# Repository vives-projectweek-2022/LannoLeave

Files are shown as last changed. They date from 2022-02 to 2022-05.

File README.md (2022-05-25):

# Lannooleaf

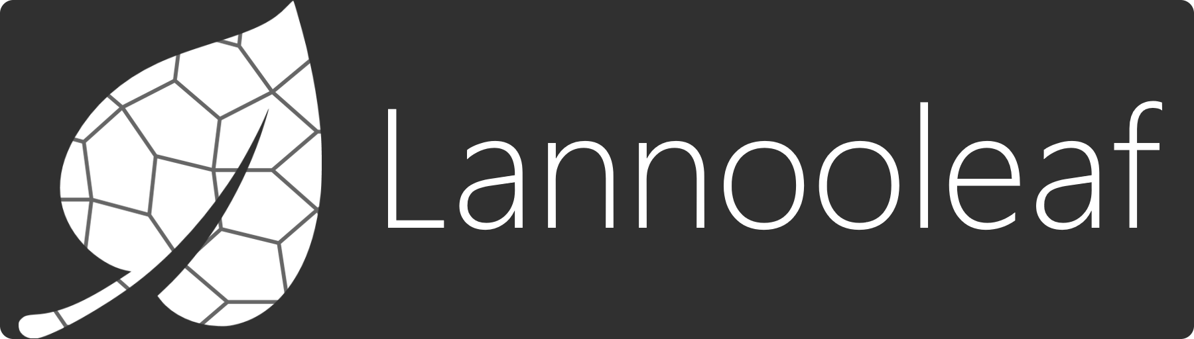
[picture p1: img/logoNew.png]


> VIVES Project Week 2022

## Project overview

<!-- bijwerken -->

* Connectable 3D-printed leaves
* PCB-design with LEDs & communications
* Use an OTS or own communication protocol
* Webpage
* Control of leds

## [Hardware](./hardware)

### [Shape](./hardware/shape/)

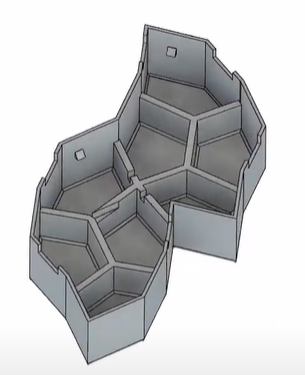
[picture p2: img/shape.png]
shape


Dit is onze shape. Een primitive unit met 8 leafs.

### [PCB](./hardware/pcb/)

<!-- afbeelding hardware -->

Iedere PCB bevat elk 16 RGB LED's en beschikken ieder over een eigen Raspberry Pi Pico en spanningsomzetter. De volledige documentatie over de hardware kan men [hier](./hardware/pcb/README.md) terugvinden.

## [Firmware](./firmware)

<!-- Joey, afbeelding Pico? -->

<!-- aanvullen -->

De firmware documentatie wordt automatisch gegenereed tijdens het build procces van de firmware. Deze is te vinden in de [firmware](./firmware/) folder waar het build procces word uitgelegd.

## [Software](./software/)

The [API](./software/api) connect with the SPI interface and communicates with the frontend, artnet and has a socket to run python processed gifs.

The [ArtNet](./software/artnet) api reicieves artnet broadcast messages ans sends them trough the websochet of the api to controll all the leds. The api mapps them depending on the coords.

The [Frontend](./software/frontend) from Jay is the webinterface and all of its files.

## Credits

### Team Members

* [Arno Schoutteten](https://github.com/madness007)
* [Jens Vanhove](https://github.com/JensVA)
* [Joey De Smet](https://github.com/JoeyDeSmet)
* [Jay D'Hulster](https://github.com/JayDHulster)

### Mentors

* [Nico De Witte](https://github.com/BioBoost)
* [Piet Cordemans](https://github.com/pcordemans)
* [Sille Van Landschoot](https://github.com/sillevl)
* [Jonas Lannoo](https://github.com/JonasLannoo)

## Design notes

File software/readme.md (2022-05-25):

# Software

## API

The [API](./api) connect with the SPI interface and communicates with the frontend, artnet and has a socket to run python processed gifs.

## ArtNet

The [ArtNet](./artnet) api reicieves artnet broadcast messages ans sends them trough the websochet of the api to controll all the leds. The api mapps them depending on the coords.

I used QLC+ (Que Light Controller plus) This is a freeware ArtNet DMX controller. There's a demo show in this directory.

ArtNet is an open protocoll that uses broadcast. So the controller sends messages thru an interface and broadcasts them in the subnet. That way everyone in the subnet can reicieve them.

This protocol is meant to run on isolated networks and is made for network noobs. It is easy to use, but not secure.

## Frontend

The [Frontend](./frontend) from Jay is the webinterface and all of its files.

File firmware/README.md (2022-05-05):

# Lannooleaf firmware

## Building the project

**Info**: The installation guide will only go over how to install tools on a debian based linux system. To build on other platforms you will have to figure that out ;).

### Requirements
- Cmake (Version >= 3.13)
- gcc-arm-none-eabi (Version used 10.2.1)
- Linux build-essentials
- Raspberry Pi Pico [sdk](https://github.com/raspberrypi/pico-sdk)
- (Optional) Visual Studio Code CMake Tools [extention](https://code.visualstudio.com/docs/cpp/cmake-linux)

#### Installing requirements

```bash
sudo apt install cmake gcc-arm-none-eabi libnewlib-arm-none-eabi build-essentials
```

**Pico-sdk**: For installation of Raspberry Pi Pico sdk reffer to there [github page](https://github.com/raspberrypi/pico-sdk)

### Building

```bash
cd /PATH/TO/Lannooleaf/firmware/
```

```bash
mkdir build
cd build
cmake ..
cmake --build .
```

Or use Visual Studio Code CMake extention to build project with a single press of a [button](https://bitly.com/98K8eH)

## Building documentation

This project automatacly generates API documentation using Doxygen and Sphinx.

If you do not want to use Sphinx, then the doxygen generated html files will be placed in /Lannooleaf/firmware/docs/Doxygen/gen_docs/html folder.

In order to build the Sphinx documentation some tools are required and have to be installed.

```bash
sudo apt-get install -y python3-sphinx
sudo apt-get install -y python3-breathe

python -m pip install exhale

pip install sphinx-book-theme
```

Once tools are installed go to the /docs/Sphinx directory and run.

```bash
make html
```

Html files will be generated an placed in /build/html folder

### Raspberry Pi Pico SDK documentation

All of Rasperry Pi Pico SDK in well documented in there [documentation](https://datasheets.raspberrypi.com/pico/raspberry-pi-pico-c-sdk.pdf)

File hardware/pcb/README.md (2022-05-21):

# PCB Lannooleaf

## Schematic

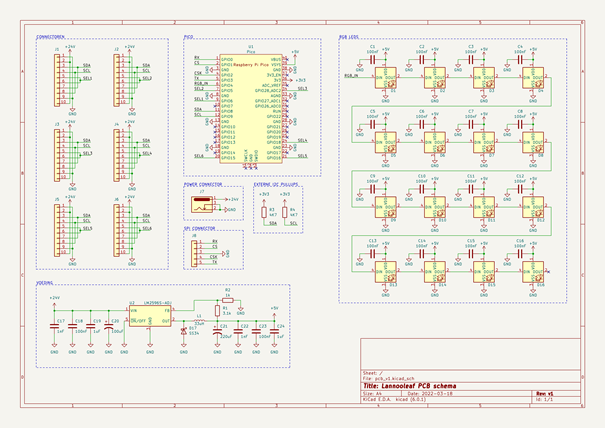
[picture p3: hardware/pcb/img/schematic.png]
Schematic


## PCB (leaf)

| Front | Back |
|---|---|
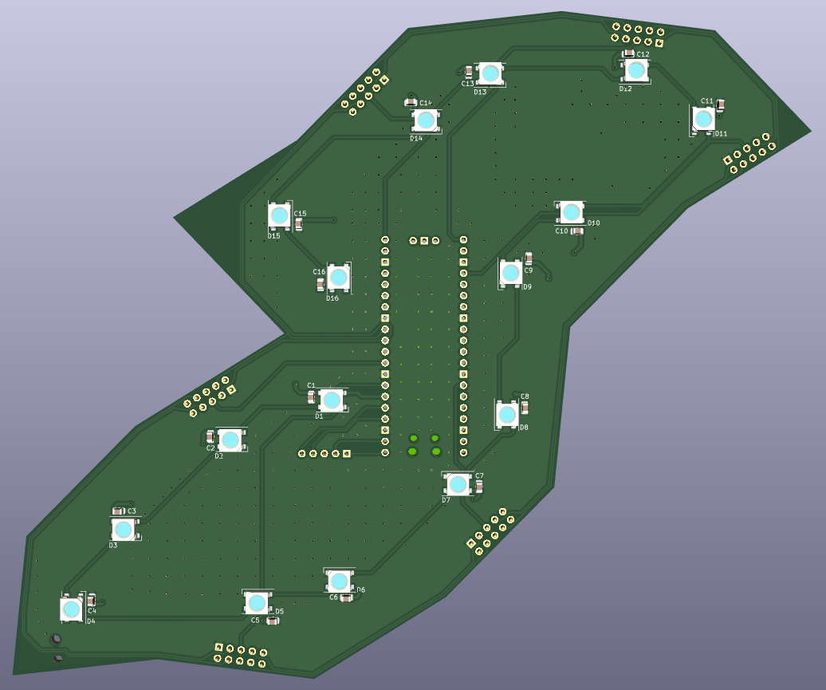
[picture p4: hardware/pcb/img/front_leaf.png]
Front
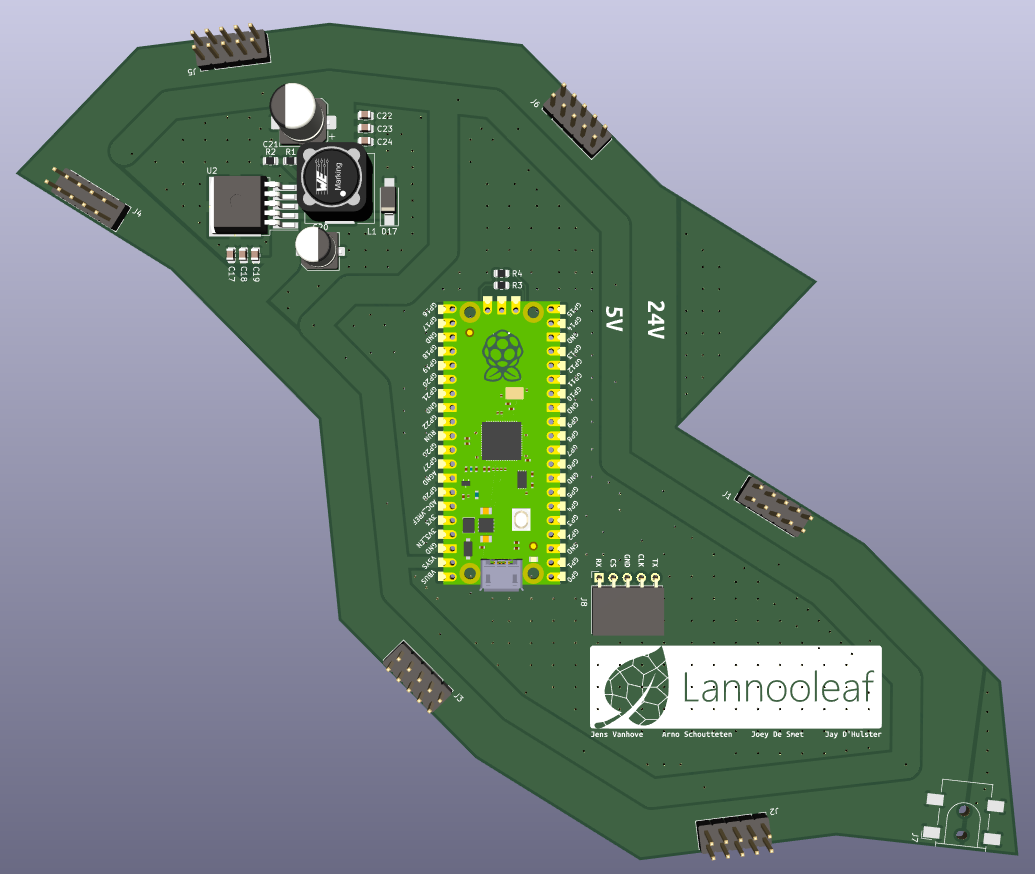
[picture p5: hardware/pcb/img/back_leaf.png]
Back
|  |  |

## PCB (verbindingsstuk)

| Front | Back |
|---|---|
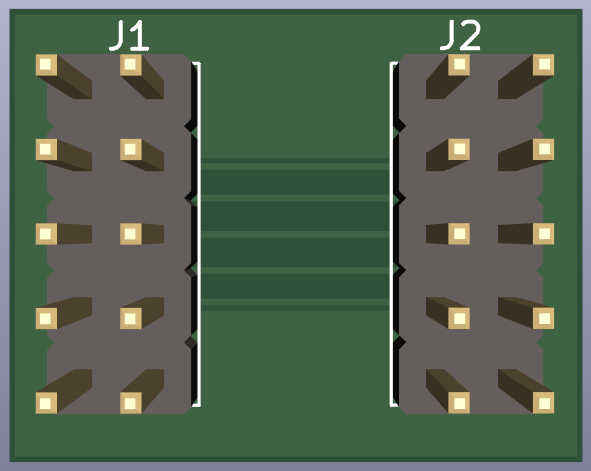
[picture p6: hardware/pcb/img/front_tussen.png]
Front
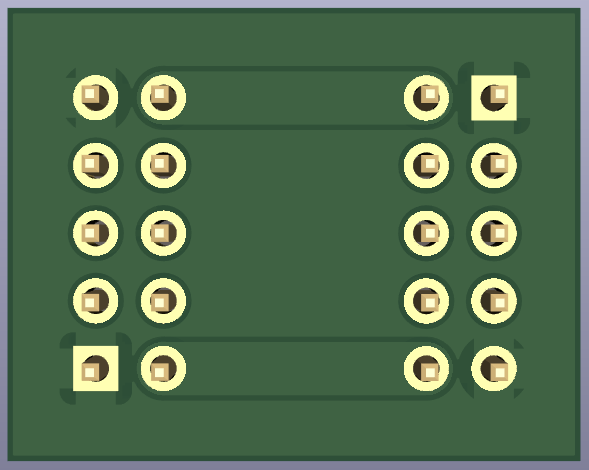
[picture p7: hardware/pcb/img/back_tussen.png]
Back
|  |  |

## Eigenschappen voedingsschakeling (LM2596)

* Bereik ingangsspanning: 4,5 - 40V (wij gebruiken 24V)
* Maximale uitgangsstroom: 3A

We hebben 16 RGB LED's die theoretisch maximaal 50mA nodig hebben. Samen met de pico die maximaal 100mA verbruikt komt dit neer op een totale stroom van `900mA` (op 5V) per leaf wat neerkomt op een `vermogen van 4,5W`. De stroom aan de 24V-kant is natuurlijk een stuk minder en bedraagt `190mA`. Het verlagen van de stroom tussen de leafs was de reden van het gebruiken van een spanningsomzetter per leaf.

## Aansluiten leafs

Om de leafs met elkaar te verbinden moeten de verbindingsstukken met hun male headers geklikt worden in de female headers van de leafs (female headers kant van Pico). Op onderstaande afbeelding kan men de functie van iedere pin zien op de leaf.

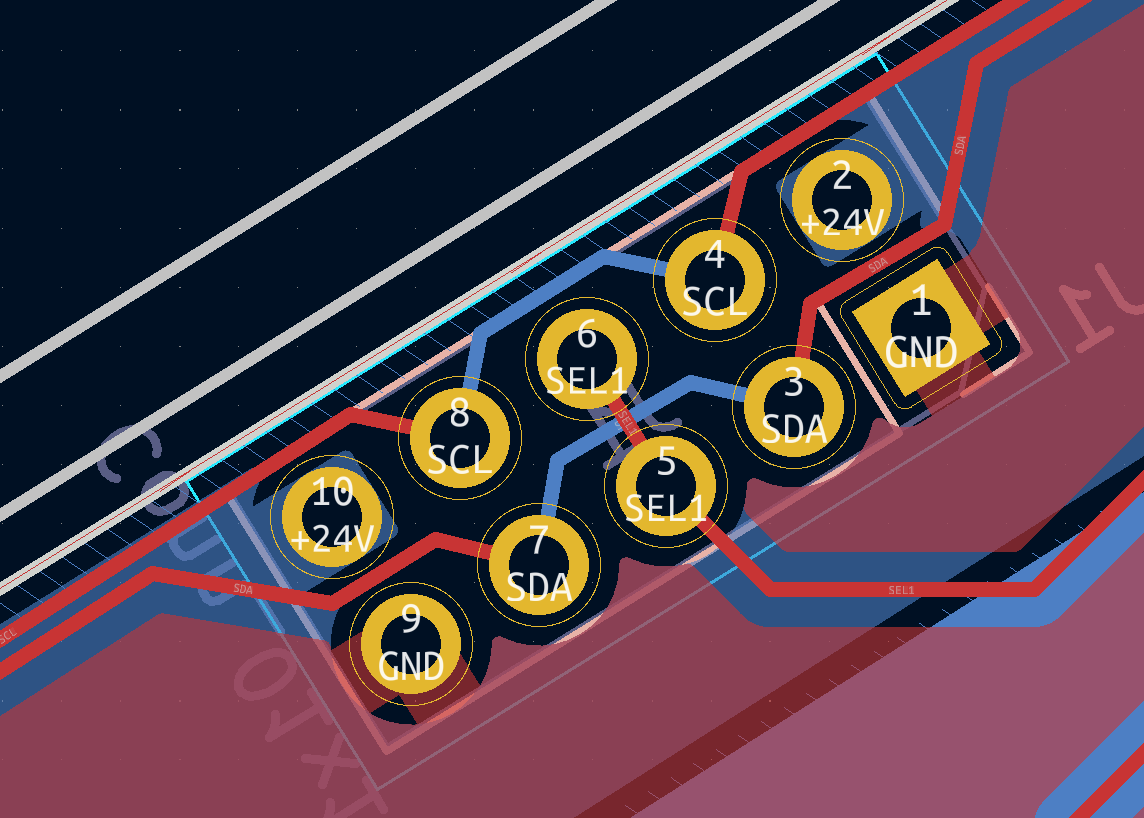
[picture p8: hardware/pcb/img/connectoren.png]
Connectoren


De buitenste 2 pinnen zijn voor het doorkoppelen van de voeding (24V en GND) tussen de leafs. De pinnen in het midden zijn beide dezelfde 'select' pin die dient voor het discovery-protocol. De overige pinnen dienen voor het doorkoppelen van de I²C-bus met SDA aan de binnenkant en SCL aan de buitenkant.

Let op dat je de spanning niet omgekeerd aansluit bij het eventueel rechtstreeks voeden van de leafs aan de headers omdat er `GEEN polariteitsbeveiliging` aanwezig is op deze versie van de PCB. Het is veiliger om de PCB's te voeden door gebruik te maken van de barrel-jack connector die men kan solderen op de voorziene plaats op de PCB.

## BOM (Bill of Materials)

| Designator | Quantity | Description | Footprint | Distributor | Ordercode | Price |
|---|---|---|---|---|---|---|
| U1 | 1 | Raspberry Pi Pico  | 2.54mm (2x20) | Farnell | [3643332](https://be.farnell.com/raspberry-pi/raspberry-pi-pico/raspberry-pi-32bit-arm-cortex/dp/3643332) | 3,27 € (1+) |
| | 2 | Headers pico  | 2.54mm (1x20) | TME | [ZL201-20G](https://www.tme.eu/be/nl/details/zl201-20g/lijsten-en-pin-achtige-stopcontacten/connfly/ds1021-1-20sf11/) | 0,17267  € (10+) |
| U2 | 1 | LM2575-05 (ADJ) | TO-263-5 | Farnell | [2534162](https://be.farnell.com/on-semiconductor/lm2596dsadjg/dc-dc-conv-buck-3a-150khz-to-263/dp/2534162) | 2,65 € (10+) |
| D1 - D16 | 16 | WS2812B addressable LEDS | 5050 | TME | [WS2812B-V5](https://www.tme.eu/be/nl/details/ws2812b-v5/led-diodes-smd-gekleurd/worldsemi/) | 0,1490 € (50+) |
| C1 - C16, C18, C23| 18 | 100nF | 0805 | Farnell | [2320821](https://be.farnell.com/multicomp/mc0805b104k101ct/cap-0-1-f-100v-10-x7r-0805/dp/2320821) | 0,048 € (250+) |
| C17, C22 | 2 | 1nF | 0805 | Farnell | [3019871](https://be.farnell.com/yageo/cc0805krx7r9bb102/cap-1000pf-50v-10-x7r-0805/dp/3019871) | 0,077 € (10+) |
| C19, C24 | 2 | 1µF | 0805 | Farnell | [3013482](https://be.farnell.com/samsung-electro-mechanics/cl21b105kbfnnne/cap-1uf-50v-mlcc-0805/dp/3013482) | 0,052 € (5+) |
| C20 | 1 | 100µF | 6,3x7,7mm | Farnell | [2611381](https://be.farnell.com/multicomp/mcvvt035m101ea6l/cap-100-f-35v-smd/dp/2611381) | 0,156 € (1+) |
| C21 | 1 | 220µF | 8x10,5mm | Farnell | [2611361](https://be.farnell.com/multicomp/mcvvt016m221fb3l/cap-220-f-16v-smd/dp/2611361) | 0,22 € (10+) |
| D17 | 1 | SS34 | DO-214AC (SMA) | Farnell | [2101195](https://be.farnell.com/multicomp/ss34a/diode-rectifier-3a-40v-do-214ac/dp/2101195) | 0,293 € (10+) |
| L1 | 1 | 33µH | 12x12x8mm | Farnell | [2288506](https://be.farnell.com/coilcraft/mss1278-333mld/inductor-33uh-3-1a-20-pwr-9-5mhz/dp/2288506) | 1,82 € (10+) |
| R1 | 1 | 3,1k | 0805 | Farnell | [2502845](https://be.farnell.com/walsin/wf08w3091btl/res-3k09-0-1-100v-0805-thin-film/dp/2502845) | 0,112 € (10+) |
| R2 | 1 | 1k | 0805 | Farnell | [2502859](https://be.farnell.com/walsin/wf08u1001btl/res-1k-0-1-100v-0805-thin-film/dp/2502859) | 0,103 € (10+) |
| J1-J6 | 6 | Pin sockets (2x5) | 2.54mm | TME | [ZL262-10DG](https://www.tme.eu/be/nl/details/zl262-10dg/lijsten-en-pin-achtige-stopcontacten/connfly/ds1023-2-5s21/) | 0,08281 € (100+) |

Volgende items zijn enkel voor de `controller` (leaf met speciale functionaliteit):

| Designator | Quantity | Description | Footprint | Distributor | Ordercode | Price |
|---|---|---|---|---|---|---|
| J7 | 1 | Power connector | | TME | [PC-GK2.5/SMD](https://www.tme.eu/be/en/details/pc-gk2.5_smd/dc-power-connectors/ninigi/) | 0,9084 € (2+) |
| J8 | 1 | Pin headers (1x5) right angle | 2.54mm | Farnell | [2356179](https://be.farnell.com/wurth-elektronik/61300511021/header-2-54mm-pin-tht-r-a-5way/dp/2356179) | 0,315 € (10+) |

Volgend item is enkel voor de `verbindingsstukken` tussen de leafs:

| Designator | Quantity | Description | Footprint | Distributor | Ordercode | Price |
|---|---|---|---|---|---|---|
| J1, J2 | 2 | Pin headers (2x5) | 2.54mm | TME | [ZL202-10G](https://www.tme.eu/be/nl/details/zl202-10g/lijsten-en-pin-achtige-stopcontacten/connfly/ds1021-2-5sf11-b/) | 0.05254 € (50+) |

Totale prijs componenten leaf: `12,9722 €`

Totale prijs componenten controller: `14,1956 €`

Totale prijs componenten verbindingsstuk: `0,10508 €`

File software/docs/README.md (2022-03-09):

# Compiling project

## Requirements
- Cmake (version >=3.13)
- gcc-arm-none-eabi
- build essentials
- [pico_sdk](https://github.com/raspberrypi/pico-sdk)

```bash

sudo apt install cmake gcc-arm-none-eabi libnewlib-arm-none-eabi build-essential

```

### Recomended
- CMake Tools VS Code extention where you can simply build by pressing one [button](https://bitly.com/98K8eH)



## Build

```bash

mkdir build && cd build
cmake ..

# Building
cd build
cmake --build .

```

## SDK documentation

- [Pi-pico-c-sdk](https://datasheets.raspberrypi.com/pico/raspberry-pi-pico-c-sdk.pdf)

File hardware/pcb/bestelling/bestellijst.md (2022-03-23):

# Bestellijst Lannooleaf

## Farnell

| Beschrijving | Footprint | Ordercode | Aantal | Prijs/stuk | Totaalprijs |
|---|---|---|---|---|---|
| Raspberry Pi Pico | 2.54mm (2x20) | [3643332](https://be.farnell.com/raspberry-pi/raspberry-pi-pico/raspberry-pi-32bit-arm-cortex/dp/3643332) | 10 | 3,27 € (1+) | 32,70 € |
| LM2575-05 (ADJ) | TO-263-5 | [2534162](https://be.farnell.com/on-semiconductor/lm2596dsadjg/dc-dc-conv-buck-3a-150khz-to-263/dp/2534162) | 10 | 2,65 € (10+) | 26,50 € |
| C - 100nF | 0805 | [2320821](https://be.farnell.com/multicomp/mc0805b104k101ct/cap-0-1-f-100v-10-x7r-0805/dp/2320821) | 250 | 0,048 € (250+) | 12,00 € |
| C - 1nF | 0805 | [3019871](https://be.farnell.com/yageo/cc0805krx7r9bb102/cap-1000pf-50v-10-x7r-0805/dp/3019871) | 20 | 0,077 € (10+) | 1,54 € |
| C - 1µF | 0805 | [3013482](https://be.farnell.com/samsung-electro-mechanics/cl21b105kbfnnne/cap-1uf-50v-mlcc-0805/dp/3013482) | 20 | 0,052 € (5+) | 1,04 € |
| C - 100µF | 6,3x7,7mm | [2611381](https://be.farnell.com/multicomp/mcvvt035m101ea6l/cap-100-f-35v-smd/dp/2611381) | 10 | 0,156 € (1+) | 1,56 € |
| C - 220µF | 8x10,5mm | [2611361](https://be.farnell.com/multicomp/mcvvt016m221fb3l/cap-220-f-16v-smd/dp/2611361) | 10 | 0,22 € (10+) | 2,20 € |
| SS34 | DO-214AC (SMA) | [2101195](https://be.farnell.com/multicomp/ss34a/diode-rectifier-3a-40v-do-214ac/dp/2101195) | 10 | 0,293 € (10+) | 2,93 € |
| L - 33µH | 12x12x8mm | [2288506](https://be.farnell.com/coilcraft/mss1278-333mld/inductor-33uh-3-1a-20-pwr-9-5mhz/dp/2288506) | 10 | 1,82 € (10+) | 18,20 € |
| R - 3,1K | 0805 | [2502845](https://be.farnell.com/walsin/wf08w3091btl/res-3k09-0-1-100v-0805-thin-film/dp/2502845) | 10 | 0,112 € (10+) | 1,12 € |
| R - 1K | 0805 | [2502859](https://be.farnell.com/walsin/wf08u1001btl/res-1k-0-1-100v-0805-thin-film/dp/2502859) | 10 | 0,103 € (10+) | 1,03 € |
| Pin headers (1x5) right angle | 2.54mm | [2356179](https://be.farnell.com/wurth-elektronik/61300511021/header-2-54mm-pin-tht-r-a-5way/dp/2356179) | 10 | 0,315 (+10) | 3,15 € |
|TOTAAL|---|---|---|---| 103,97 € |

## TME

| Beschrijving | Footprint | Ordercode | Aantal | Prijs/stuk | Totaalprijs |
|---|---|---|---|---|---|
| Headers pico | 2.54mm (1x20) | [ZL201-20G](https://www.tme.eu/be/nl/details/zl201-20g/lijsten-en-pin-achtige-stopcontacten/connfly/ds1021-1-20sf11/) | 50 | 0,13685 € (50+) | 6,8425 € |
| WS2812B addressable LEDS | 5050 | [WS2812B-V5](https://www.tme.eu/be/nl/details/ws2812b-v5/led-diodes-smd-gekleurd/worldsemi/) | 250 | 0,1270 € (+250) | 31,75 € |
| Pin sockets (2x5) | 2.54mm | [ZL262-10DG](https://www.tme.eu/be/nl/details/zl262-10dg/lijsten-en-pin-achtige-stopcontacten/connfly/ds1023-2-5s21/) | 100 | 0,08269 (+100) | 8,269 € |
| Power connector | | [PC-GK2.5/SMD](https://www.tme.eu/be/en/details/pc-gk2.5_smd/dc-power-connectors/ninigi/) | 2 | 0,9071 (+2) | 1,8142 € |
| Pin headers (2x5) | 2.54mm | [ZL202-10G](https://www.tme.eu/be/nl/details/zl202-10g/lijsten-en-pin-achtige-stopcontacten/connfly/ds1021-2-5sf11-b/) | 50 | 0,05247 (+50) | 2,6235 € |
|TOTAAL|---|---|---|---| 51,2992 € |

## PCB

10 leaf PCB's
25 tussenstuk PCB's

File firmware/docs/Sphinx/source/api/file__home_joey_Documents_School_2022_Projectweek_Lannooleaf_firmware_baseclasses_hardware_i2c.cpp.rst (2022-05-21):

.. _file__home_joey_Documents_School_2022_Projectweek_Lannooleaf_firmware_baseclasses_hardware_i2c.cpp:

File i2c.cpp
============

|exhale_lsh| :ref:`Parent directory <dir__home_joey_Documents_School_2022_Projectweek_Lannooleaf_firmware_baseclasses_hardware>` (``/home/joey/Documents/School_2022/Projectweek/Lannooleaf/firmware/baseclasses/hardware``)

.. |exhale_lsh| unicode:: U+021B0 .. UPWARDS ARROW WITH TIP LEFTWARDS

.. contents:: Contents
   :local:
   :backlinks: none

Definition (``/home/joey/Documents/School_2022/Projectweek/Lannooleaf/firmware/baseclasses/hardware/i2c.cpp``)
--------------------------------------------------------------------------------------------------------------

Includes
--------

- ``i2c.hpp`` (:ref:`file__home_joey_Documents_School_2022_Projectweek_Lannooleaf_firmware_baseclasses_hardware_include_i2c.hpp`)

Namespaces
----------

- :ref:`namespace_Lannooleaf`

- :ref:`namespace_Lannooleaf__baseclasses`

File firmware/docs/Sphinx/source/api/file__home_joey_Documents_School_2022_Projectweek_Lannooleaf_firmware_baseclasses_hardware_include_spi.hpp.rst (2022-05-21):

.. _file__home_joey_Documents_School_2022_Projectweek_Lannooleaf_firmware_baseclasses_hardware_include_spi.hpp:

File spi.hpp
============

|exhale_lsh| :ref:`Parent directory <dir__home_joey_Documents_School_2022_Projectweek_Lannooleaf_firmware_baseclasses_hardware_include>` (``/home/joey/Documents/School_2022/Projectweek/Lannooleaf/firmware/baseclasses/hardware/include``)

.. |exhale_lsh| unicode:: U+021B0 .. UPWARDS ARROW WITH TIP LEFTWARDS

SPI base class. 

.. contents:: Contents
   :local:
   :backlinks: none

Definition (``/home/joey/Documents/School_2022/Projectweek/Lannooleaf/firmware/baseclasses/hardware/include/spi.hpp``)
----------------------------------------------------------------------------------------------------------------------

Detailed Description
--------------------

Joey De Smet (Joey@de-smet.org) 

0.1 

2022-05-07

Copyright (c) 2022 

Includes
--------

- ``hardware/irq.h``

- ``hardware/spi.h``

- ``pico/stdlib.h``

- ``stdexcept``

- ``stdint.h``

Included By
-----------

- :ref:`file__home_joey_Documents_School_2022_Projectweek_Lannooleaf_firmware_baseclasses_hardware_spi.cpp`

- :ref:`file__home_joey_Documents_School_2022_Projectweek_Lannooleaf_firmware_hardware_include_spi_slave.hpp`

Namespaces
----------

- :ref:`namespace_Lannooleaf`

- :ref:`namespace_Lannooleaf__baseclasses`

Classes
-------

- :ref:`exhale_class_classLannooleaf_1_1baseclasses_1_1SPI`

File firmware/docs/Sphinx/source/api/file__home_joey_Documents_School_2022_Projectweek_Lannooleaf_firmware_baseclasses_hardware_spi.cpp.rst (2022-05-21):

.. _file__home_joey_Documents_School_2022_Projectweek_Lannooleaf_firmware_baseclasses_hardware_spi.cpp:

File spi.cpp
============

|exhale_lsh| :ref:`Parent directory <dir__home_joey_Documents_School_2022_Projectweek_Lannooleaf_firmware_baseclasses_hardware>` (``/home/joey/Documents/School_2022/Projectweek/Lannooleaf/firmware/baseclasses/hardware``)

.. |exhale_lsh| unicode:: U+021B0 .. UPWARDS ARROW WITH TIP LEFTWARDS

.. contents:: Contents
   :local:
   :backlinks: none

Definition (``/home/joey/Documents/School_2022/Projectweek/Lannooleaf/firmware/baseclasses/hardware/spi.cpp``)
--------------------------------------------------------------------------------------------------------------

Includes
--------

- ``spi.hpp`` (:ref:`file__home_joey_Documents_School_2022_Projectweek_Lannooleaf_firmware_baseclasses_hardware_include_spi.hpp`)

Namespaces
----------

- :ref:`namespace_Lannooleaf`

- :ref:`namespace_Lannooleaf__baseclasses`

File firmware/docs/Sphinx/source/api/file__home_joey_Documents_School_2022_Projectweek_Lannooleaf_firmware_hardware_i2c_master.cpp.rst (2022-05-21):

.. _file__home_joey_Documents_School_2022_Projectweek_Lannooleaf_firmware_hardware_i2c_master.cpp:

File i2c_master.cpp
===================

|exhale_lsh| :ref:`Parent directory <dir__home_joey_Documents_School_2022_Projectweek_Lannooleaf_firmware_hardware>` (``/home/joey/Documents/School_2022/Projectweek/Lannooleaf/firmware/hardware``)

.. |exhale_lsh| unicode:: U+021B0 .. UPWARDS ARROW WITH TIP LEFTWARDS

.. contents:: Contents
   :local:
   :backlinks: none

Definition (``/home/joey/Documents/School_2022/Projectweek/Lannooleaf/firmware/hardware/i2c_master.cpp``)
---------------------------------------------------------------------------------------------------------

Includes
--------

- ``i2c_master.hpp`` (:ref:`file__home_joey_Documents_School_2022_Projectweek_Lannooleaf_firmware_hardware_include_i2c_master.hpp`)

Namespaces
----------

- :ref:`namespace_Lannooleaf`

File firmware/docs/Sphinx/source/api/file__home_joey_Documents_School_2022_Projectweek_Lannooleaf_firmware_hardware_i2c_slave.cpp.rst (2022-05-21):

.. _file__home_joey_Documents_School_2022_Projectweek_Lannooleaf_firmware_hardware_i2c_slave.cpp:

File i2c_slave.cpp
==================

|exhale_lsh| :ref:`Parent directory <dir__home_joey_Documents_School_2022_Projectweek_Lannooleaf_firmware_hardware>` (``/home/joey/Documents/School_2022/Projectweek/Lannooleaf/firmware/hardware``)

.. |exhale_lsh| unicode:: U+021B0 .. UPWARDS ARROW WITH TIP LEFTWARDS

.. contents:: Contents
   :local:
   :backlinks: none

Definition (``/home/joey/Documents/School_2022/Projectweek/Lannooleaf/firmware/hardware/i2c_slave.cpp``)
--------------------------------------------------------------------------------------------------------

Includes
--------

- ``i2c_slave.hpp`` (:ref:`file__home_joey_Documents_School_2022_Projectweek_Lannooleaf_firmware_hardware_include_i2c_slave.hpp`)

Namespaces
----------

- :ref:`namespace_Lannooleaf`

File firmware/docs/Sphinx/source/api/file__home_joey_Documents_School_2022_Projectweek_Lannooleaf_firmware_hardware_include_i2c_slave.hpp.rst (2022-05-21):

.. _file__home_joey_Documents_School_2022_Projectweek_Lannooleaf_firmware_hardware_include_i2c_slave.hpp:

File i2c_slave.hpp
==================

|exhale_lsh| :ref:`Parent directory <dir__home_joey_Documents_School_2022_Projectweek_Lannooleaf_firmware_hardware_include>` (``/home/joey/Documents/School_2022/Projectweek/Lannooleaf/firmware/hardware/include``)

.. |exhale_lsh| unicode:: U+021B0 .. UPWARDS ARROW WITH TIP LEFTWARDS

I2C Slave class to use ri pi pico as i2c slave. 

.. contents:: Contents
   :local:
   :backlinks: none

Definition (``/home/joey/Documents/School_2022/Projectweek/Lannooleaf/firmware/hardware/include/i2c_slave.hpp``)
----------------------------------------------------------------------------------------------------------------

Detailed Description
--------------------

Joey De Smet (Joey@de-smet.org) 

0.1 

2022-05-04

Copyright 2022 Joey De Smet

Licensed under the Apache License, Version 2.0 (the "License"); you may not use this file except in compliance with the License. You may obtain a copy of the License at    http://www.apache.org/licenses/LICENSE-2.0
 Unless required by applicable law or agreed to in writing, software distributed under the License is distributed on an "AS IS" BASIS, WITHOUT WARRANTIES OR CONDITIONS OF ANY KIND, either express or implied. See the License for the specific language governing permissions and limitations under the License. 

Includes
--------

- ``array``

- ``buffered_communicator.hpp`` (:ref:`file__home_joey_Documents_School_2022_Projectweek_Lannooleaf_firmware_baseclasses_communication_include_buffered_communicator.hpp`)

- ``hardware/i2c.h``

- ``i2c.hpp`` (:ref:`file__home_joey_Documents_School_2022_Projectweek_Lannooleaf_firmware_baseclasses_hardware_include_i2c.hpp`)

- ``i2c_slave_lib.h``

- ``pico/stdlib.h``

- ``pico/util/queue.h``

- ``queue``

- ``stdexcept``

- ``stdint.h``

Included By
-----------

- :ref:`file__home_joey_Documents_School_2022_Projectweek_Lannooleaf_firmware_hardware_i2c_slave.cpp`

- :ref:`file__home_joey_Documents_School_2022_Projectweek_Lannooleaf_firmware_Lannooleaf_include_leaf.hpp`

Namespaces
----------

- :ref:`namespace_Lannooleaf`

Classes
-------

- :ref:`exhale_class_classLannooleaf_1_1I2CSlave`

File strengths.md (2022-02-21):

# Interesses

Dit zijn de sterktes / interesses van ieder van ons.
Op basis hiervan worden de taken wat verdeeld.

## geef een score van 1 tot 5 per item

| |Arno|Jens|Jay |Joey|verantwoordelijke(n)|
|--- |--- |--- |--- |--- |--- |
|software | 5  | 2  |2.5 | 5  | Arno, Joey |
|hardware | 3  | 5  |2.5 | 1  | - |
|-- 3d modeling | 4  | 3  |1 | 1  | Arno |
|-- shape | 3  | 3  |3 | 3  | Arno |
|pcb design | 2  | 5  |4 | 3  | Jay, Jens |
|-- power management | 2  | 4  |2 | 3  | Jay, Jens |
|-- componentkeuze | 3  | 4  |2.5 | 3  | Jay, Jens |
|-- soort led aansturing | 2  | 4  |3 | 3  | - |
|materiaalbeheer | 3  | 3  |2.5 | 3  | Arno |
|firmware | 4  | 4  |2.5 | 5  | Joey |
|protocol | 4  | 4  |2 | 5  | Joey |

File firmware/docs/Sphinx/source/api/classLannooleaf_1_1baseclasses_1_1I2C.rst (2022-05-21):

.. _exhale_class_classLannooleaf_1_1baseclasses_1_1I2C:

Class I2C
=========

- Defined in :ref:`file__home_joey_Documents_School_2022_Projectweek_Lannooleaf_firmware_baseclasses_hardware_include_i2c.hpp`

Inheritance Relationships
-------------------------

Derived Types
*************

- ``public Lannooleaf::I2CMaster`` (:ref:`exhale_class_classLannooleaf_1_1I2CMaster`)
- ``public Lannooleaf::I2CSlave`` (:ref:`exhale_class_classLannooleaf_1_1I2CSlave`)

Class Documentation
-------------------

.. doxygenclass:: Lannooleaf::baseclasses::I2C
   :project: Lannooleaf firmware
   :members:
   :protected-members:
   :undoc-members:

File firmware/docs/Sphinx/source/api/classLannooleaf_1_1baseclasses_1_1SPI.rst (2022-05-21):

.. _exhale_class_classLannooleaf_1_1baseclasses_1_1SPI:

Class SPI
=========

- Defined in :ref:`file__home_joey_Documents_School_2022_Projectweek_Lannooleaf_firmware_baseclasses_hardware_include_spi.hpp`

Inheritance Relationships
-------------------------

Derived Type
************

- ``public Lannooleaf::SPISlave`` (:ref:`exhale_class_classLannooleaf_1_1SPISlave`)

Class Documentation
-------------------

.. doxygenclass:: Lannooleaf::baseclasses::SPI
   :project: Lannooleaf firmware
   :members:
   :protected-members:
   :undoc-members:

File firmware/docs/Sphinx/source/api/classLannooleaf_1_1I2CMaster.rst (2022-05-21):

.. _exhale_class_classLannooleaf_1_1I2CMaster:

Class I2CMaster
===============

- Defined in :ref:`file__home_joey_Documents_School_2022_Projectweek_Lannooleaf_firmware_hardware_include_i2c_master.hpp`

Inheritance Relationships
-------------------------

Base Types
**********

- ``public Lannooleaf::baseclasses::I2C`` (:ref:`exhale_class_classLannooleaf_1_1baseclasses_1_1I2C`)
- ``public Lannooleaf::baseclasses::AddressedCommunicator`` (:ref:`exhale_class_classLannooleaf_1_1baseclasses_1_1AddressedCommunicator`)

Class Documentation
-------------------

.. doxygenclass:: Lannooleaf::I2CMaster
   :project: Lannooleaf firmware
   :members:
   :protected-members:
   :undoc-members:

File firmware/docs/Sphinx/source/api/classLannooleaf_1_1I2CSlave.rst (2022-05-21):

.. _exhale_class_classLannooleaf_1_1I2CSlave:

Class I2CSlave
==============

- Defined in :ref:`file__home_joey_Documents_School_2022_Projectweek_Lannooleaf_firmware_hardware_include_i2c_slave.hpp`

Inheritance Relationships
-------------------------

Base Types
**********

- ``public Lannooleaf::baseclasses::I2C`` (:ref:`exhale_class_classLannooleaf_1_1baseclasses_1_1I2C`)
- ``public Lannooleaf::baseclasses::BufferedCommunicator`` (:ref:`exhale_class_classLannooleaf_1_1baseclasses_1_1BufferedCommunicator`)

Class Documentation
-------------------

.. doxygenclass:: Lannooleaf::I2CSlave
   :project: Lannooleaf firmware
   :members:
   :protected-members:
   :undoc-members:

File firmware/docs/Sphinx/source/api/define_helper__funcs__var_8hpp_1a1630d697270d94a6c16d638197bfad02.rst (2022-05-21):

.. _exhale_define_helper__funcs__var_8hpp_1a1630d697270d94a6c16d638197bfad02:

Define I2C_CONTOLLER_PLACEHOLDER_ADDRESS
========================================

- Defined in :ref:`file__home_joey_Documents_School_2022_Projectweek_Lannooleaf_firmware_helpers_include_helper_funcs_var.hpp`

Define Documentation
--------------------

.. doxygendefine:: I2C_CONTOLLER_PLACEHOLDER_ADDRESS
   :project: Lannooleaf firmware

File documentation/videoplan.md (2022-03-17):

## Video plan Lannooleaf

> Comments should be in a quote with `> text`

### Intro

Make logo slide in, start some music up, afterwards someone starts speaking and shortly introduces the audience to the project.

### Build process

Tell the audience about the ideas at the start, pitches, and initial setup.

Afterwards show progress being made; development of web interface, 3D Modelling, PCB design and coding.
Also show testing of the hardware/software.

The VO will tell the audience about the web development, 3D modelling, PCB design etc... while the footage is being shown. 

### Finished product

Tell the audience how it works and how to use it, and demonstrate the Lannooleaf.

### Credits?

Tell people (with text) where to find the repo and documentation.

Name every project member and the mentors, put down some logo's and fade out

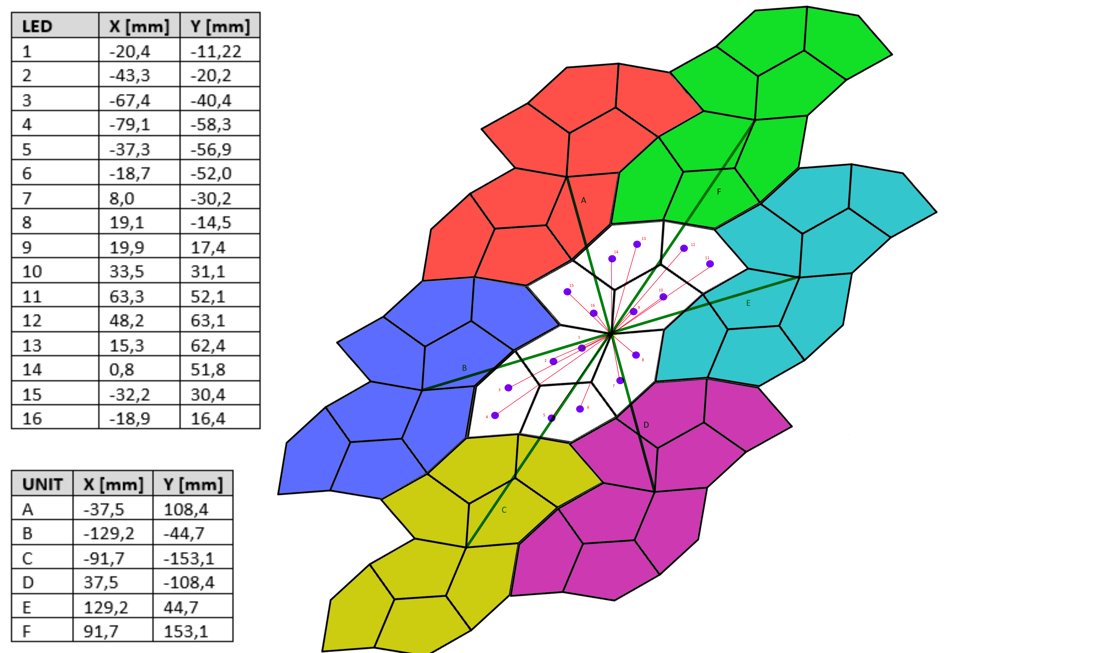
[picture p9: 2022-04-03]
hardware/shape/afstanden.png

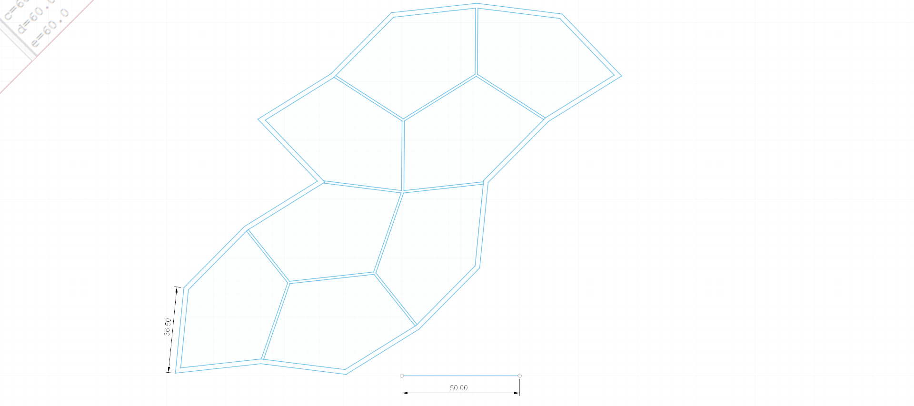
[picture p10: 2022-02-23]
hardware/shape/LannooLeave_blueprint.png

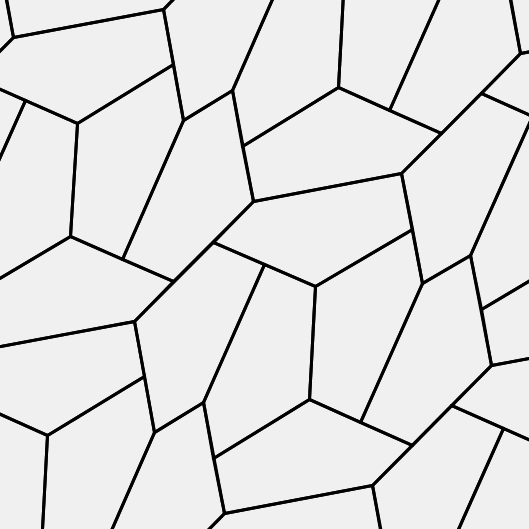
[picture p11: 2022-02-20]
hardware/shape/tiling_no_color.png

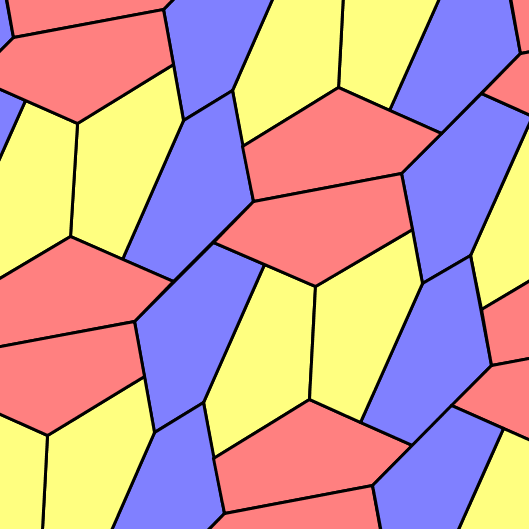
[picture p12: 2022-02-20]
hardware/shape/tiling.png

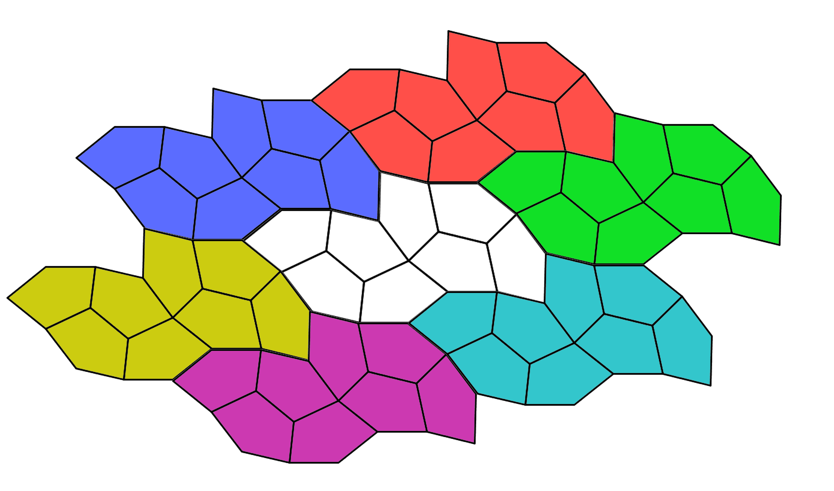
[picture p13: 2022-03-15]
hardware/shape/colorleafs.png

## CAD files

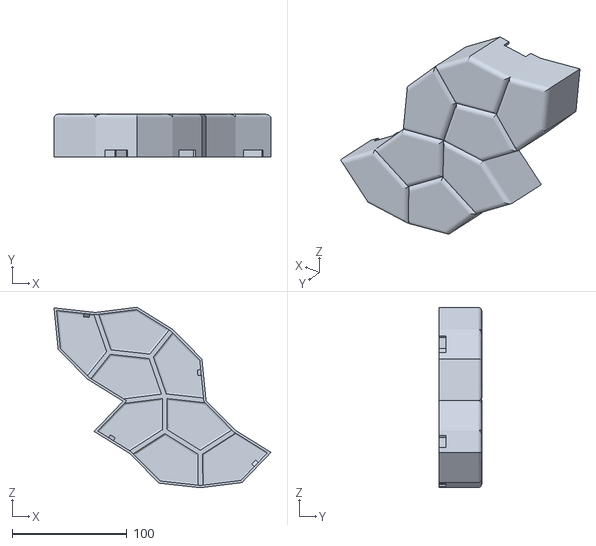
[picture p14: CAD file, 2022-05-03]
hardware/shape/prototype3.stl
189.5 x 37.3 x 157.6

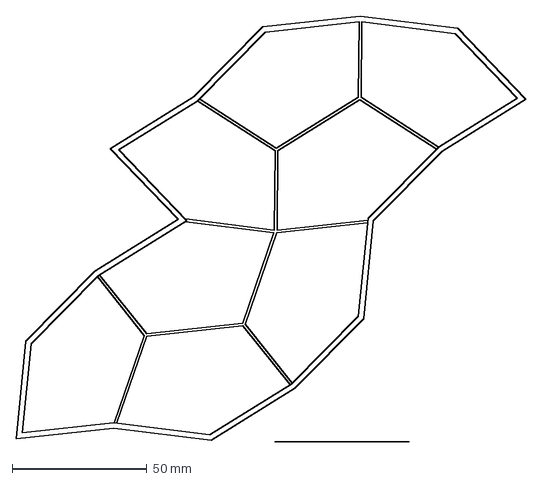
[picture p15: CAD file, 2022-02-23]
hardware/shape/pcb-inline.dxf
189.5 x 158.2 mm

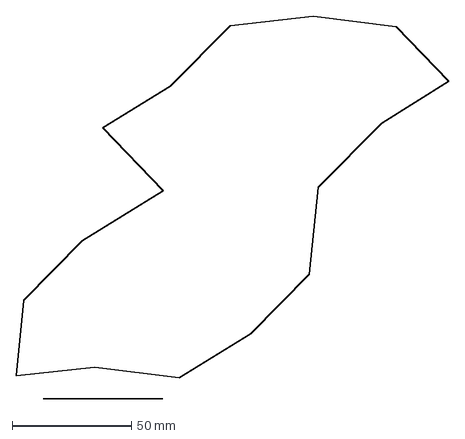
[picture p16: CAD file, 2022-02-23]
hardware/shape/pcb-outliune.dxf
181.4 x 160.2 mm

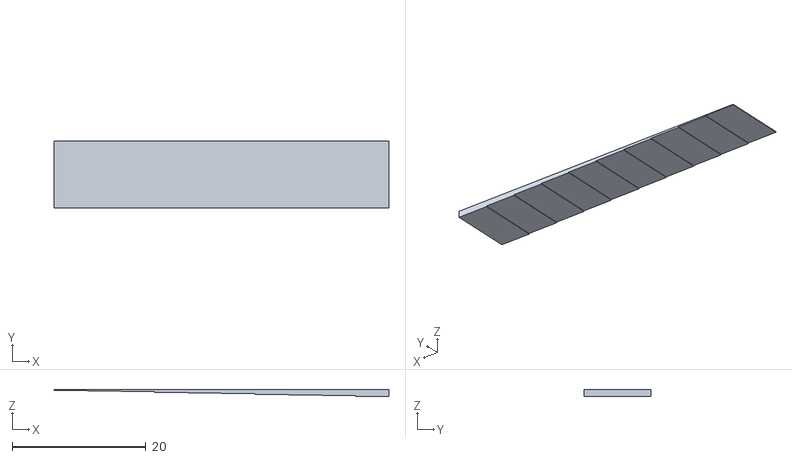
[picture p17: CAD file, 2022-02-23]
hardware/shape/tolerance_check.stl
50.0 x 10.0 x 1.00

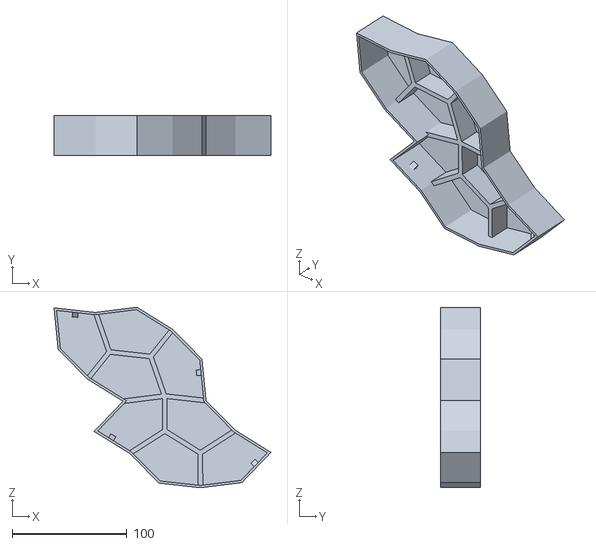
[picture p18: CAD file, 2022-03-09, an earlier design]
hardware/shape/prototype1.stl
189.5 x 35.3 x 157.6

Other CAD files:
hardware/shape/prototype2.stl
hardware/shape/LannooLeaf_v1.ipt
hardware/shape/LannooLeave v4.f3d
hardware/shape/Lannoof v7.f3d

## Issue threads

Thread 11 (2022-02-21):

classe master (sender)

madness007, 2022-02-21:
maak een classe waaraan je kan zeggen: ControllLed("leaveId", R, G, B)
(maak gebruik van het unieke leave id, de positionering moet hogeraf worden opgevangen

JoeyDeSmet, 2022-03-09:
closed on accident

Closed 2022-04-14.

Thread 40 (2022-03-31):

SPI_Write to Pi4

JoeyDeSmet, 2022-03-31:

JoeyDeSmet, 2022-03-31:
SPI writes are not  behaving as expected.

JoeyDeSmet, 2022-04-02:
When Pi reads from Pico, received data is shifted by 4 bytes to the right. So first 4 bytes are always 0x00, then expected bytes apear and flow over to nexttime Pi reads from pico.

Closed 2022-04-14.

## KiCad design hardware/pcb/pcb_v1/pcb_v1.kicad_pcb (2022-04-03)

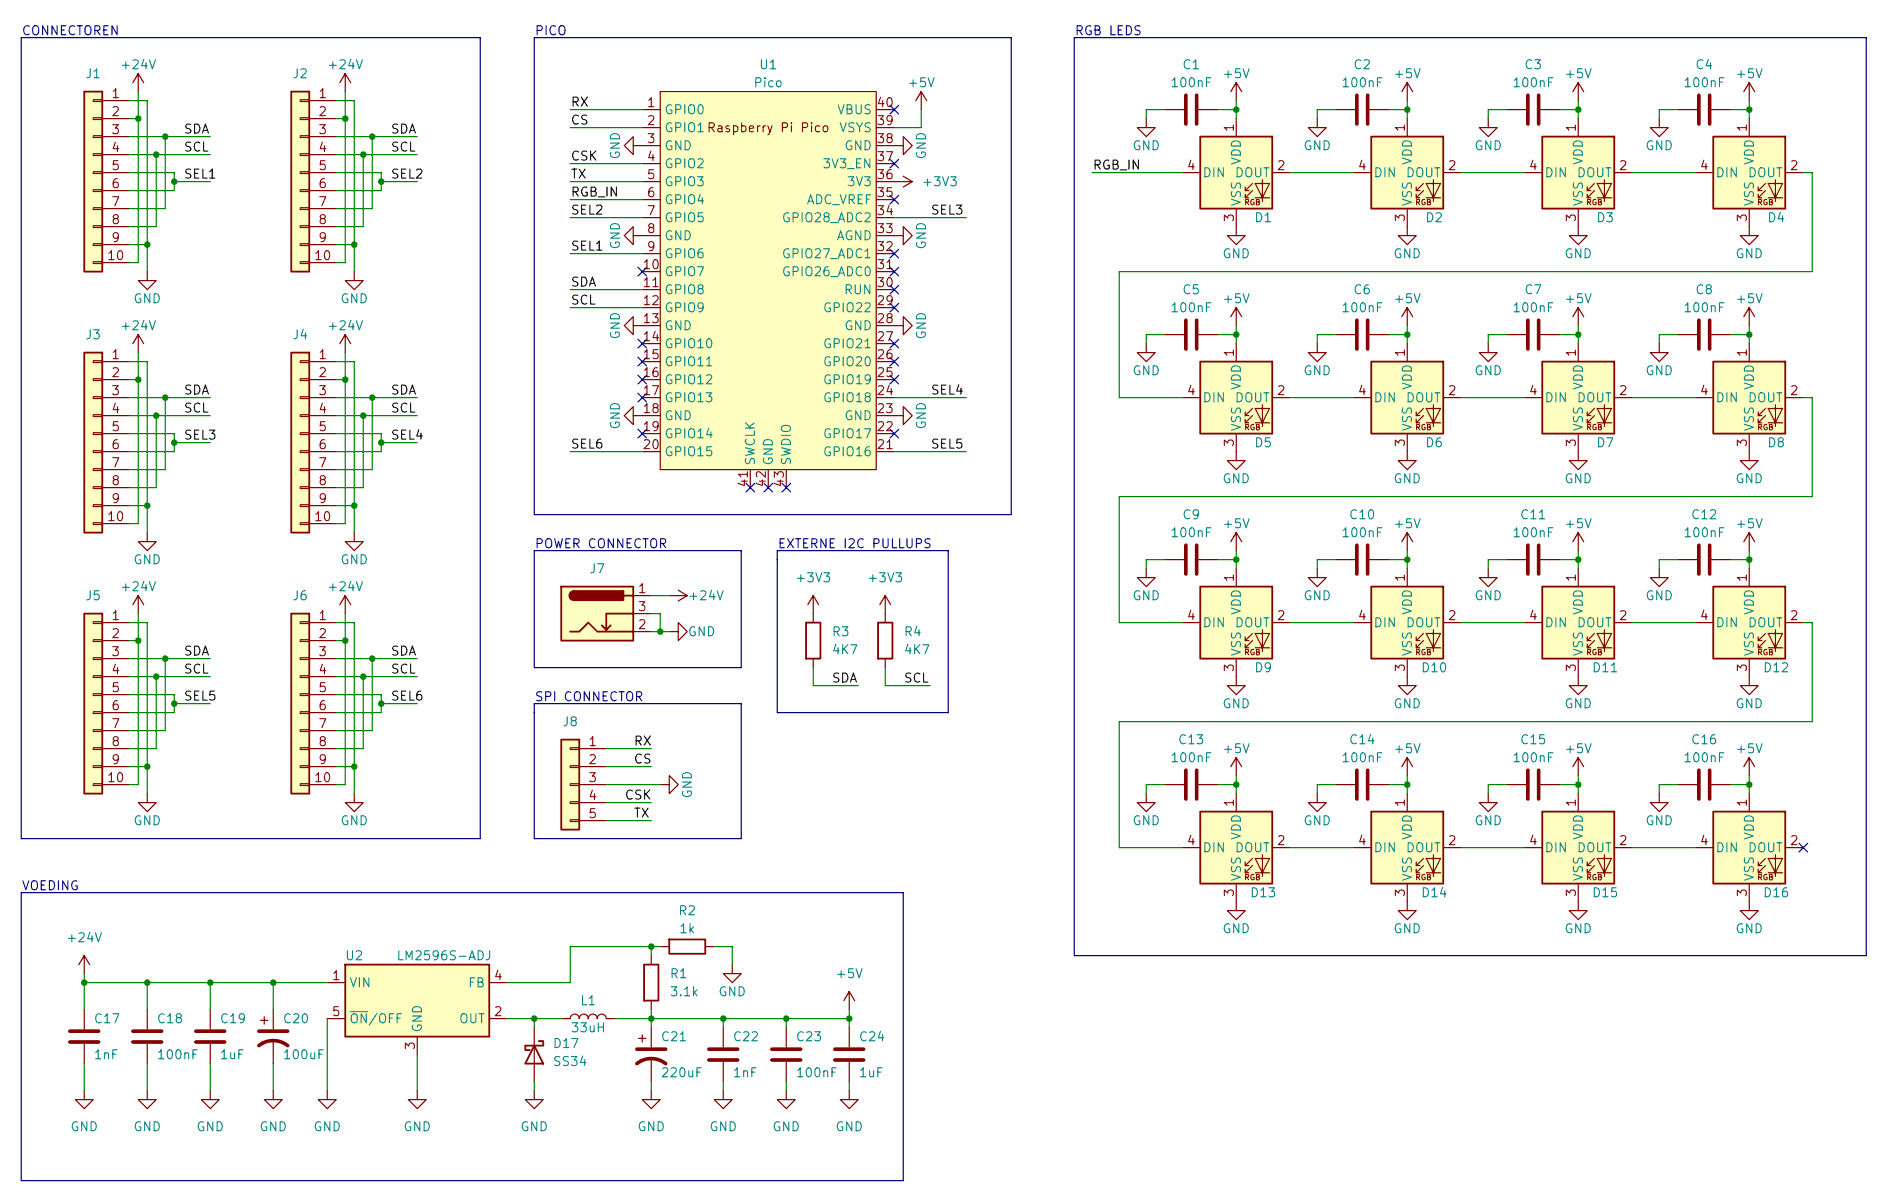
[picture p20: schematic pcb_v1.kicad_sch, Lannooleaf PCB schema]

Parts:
C1, C2, C3, C4, C5, C6, C7, C8, C9, C10, C11, C12, C13, C14, C15, C16, C18, C23: 100nF; C_0805_2012Metric
C17, C22: 1nF; C_0805_2012Metric
C19, C24: 1uF; C_0805_2012Metric
C20: 100uF; CP_Elec_6.3x7.7
C21: 220uF; CP_Elec_8x10.5
D1, D2, D3, D4, D5, D6, D7, D8, D9, D10, D11, D12, D13, D14, D15, D16: WS2812B; LED_WS2812B_PLCC4_5.0x5.0mm_P3.2mm
D17: SS34; D_SMA_Handsoldering
J1, J2, J3, J4, J5, J6: Conn_01x10; PinHeader_2x05_P2.54mm_Vertical
J7: Barrel_Jack_Switch; BarrelJack_CLIFF_FC681465S_SMT_Horizontal
J8: Conn_01x05; PinSocket_1x05_P2.54mm_Horizontal
L1: 33uH; L_12x12mm_H8mm
R1: 3.1k; R_0805_2012Metric
R2: 1k; R_0805_2012Metric
R3, R4: 4K7; R_0805_2012Metric
U1: Pico; RPi_Pico_SMD_TH
U2: LM2596S-ADJ; TO-263-5_TabPin3

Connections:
+3V3: R3.1, R4.1, U1.36 (3V3)
+5V: C1.2, C2.2, C3.2, C4.2, C5.2, C6.2, C7.2, C8.2, C9.2, C10.2, C11.2, C12.2, C13.2, C14.2, C15.2, C16.2, C21.1, C22.1, C23.1, C24.1, D1.1 (VDD), D2.1 (VDD), D3.1 (VDD), D4.1 (VDD), D5.1 (VDD), D6.1 (VDD), D7.1 (VDD), D8.1 (VDD), D9.1 (VDD), D10.1 (VDD), D11.1 (VDD), D12.1 (VDD), D13.1 (VDD), D14.1 (VDD), D15.1 (VDD), D16.1 (VDD), L1.2, R1.2, U1.39 (VSYS)
+24V: C17.1, C18.1, C19.1, C20.1, J1.2, J1.10, J2.2, J2.10, J3.2, J3.10, J4.2, J4.10, J5.2, J5.10, J6.2, J6.10, J7.1, U2.1 (VIN)
/CS: J8.2, U1.2 (GPIO1)
/CSK: J8.4, U1.4 (GPIO2)
/RGB_IN: D1.4 (DIN), U1.6 (GPIO4)
/RX: J8.1, U1.1 (GPIO0)
/SCL: J1.4, J1.8, J2.4, J2.8, J3.4, J3.8, J4.4, J4.8, J5.4, J5.8, J6.4, J6.8, R4.2, U1.12 (GPIO9)
/SDA: J1.3, J1.7, J2.3, J2.7, J3.3, J3.7, J4.3, J4.7, J5.3, J5.7, J6.3, J6.7, R3.2, U1.11 (GPIO8)
/SEL1: J1.5, J1.6, U1.9 (GPIO6)
/SEL2: J2.5, J2.6, U1.7 (GPIO5)
/SEL3: J3.5, J3.6, U1.34 (GPIO28_ADC2)
/SEL4: J4.5, J4.6, U1.24 (GPIO18)
/SEL5: J5.5, J5.6, U1.21 (GPIO16)
/SEL6: J6.5, J6.6, U1.20 (GPIO15)
/TX: J8.5, U1.5 (GPIO3)
GND: C1.1, C2.1, C3.1, C4.1, C5.1, C6.1, C7.1, C8.1, C9.1, C10.1, C11.1, C12.1, C13.1, C14.1, C15.1, C16.1, C17.2, C18.2, C19.2, C20.2, C21.2, C22.2, C23.2, C24.2, D1.3 (VSS), D2.3 (VSS), D3.3 (VSS), D4.3 (VSS), D5.3 (VSS), D6.3 (VSS), D7.3 (VSS), D8.3 (VSS), D9.3 (VSS), D10.3 (VSS), D11.3 (VSS), D12.3 (VSS), D13.3 (VSS), D14.3 (VSS), D15.3 (VSS), D16.3 (VSS), D17.2 (A), J1.1, J1.9, J2.1, J2.9, J3.1, J3.9, J4.1, J4.9, J5.1, J5.9, J6.1, J6.9, J7.2, J7.3, J8.3, R2.1, U1.3 (GND), U1.8 (GND), U1.13 (GND), U1.18 (GND), U1.23 (GND), U1.28 (GND), U1.33 (AGND), U1.38 (GND), U2.3 (GND), U2.5 (~ON/OFF)
unnamed: D1.2 (DOUT), D2.4 (DIN)
unnamed: D2.2 (DOUT), D3.4 (DIN)
unnamed: D3.2 (DOUT), D4.4 (DIN)
unnamed: D4.2 (DOUT), D5.4 (DIN)
unnamed: D5.2 (DOUT), D6.4 (DIN)
unnamed: D6.2 (DOUT), D7.4 (DIN)
unnamed: D7.2 (DOUT), D8.4 (DIN)
unnamed: D8.2 (DOUT), D9.4 (DIN)
unnamed: D10.2 (DOUT), D11.4 (DIN)
unnamed: D9.2 (DOUT), D10.4 (DIN)
unnamed: D11.2 (DOUT), D12.4 (DIN)
unnamed: D12.2 (DOUT), D13.4 (DIN)
unnamed: D13.2 (DOUT), D14.4 (DIN)
unnamed: D14.2 (DOUT), D15.4 (DIN)
unnamed: D15.2 (DOUT), D16.4 (DIN)
unnamed: D17.1 (K), L1.1, U2.2 (OUT)
unnamed: R1.1, R2.2, U2.4 (FB)

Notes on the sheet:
POWER CONNECTOR
EXTERNE I2C PULLUPS
VOEDING
PICO
CONNECTOREN
SPI CONNECTOR
RGB LEDS

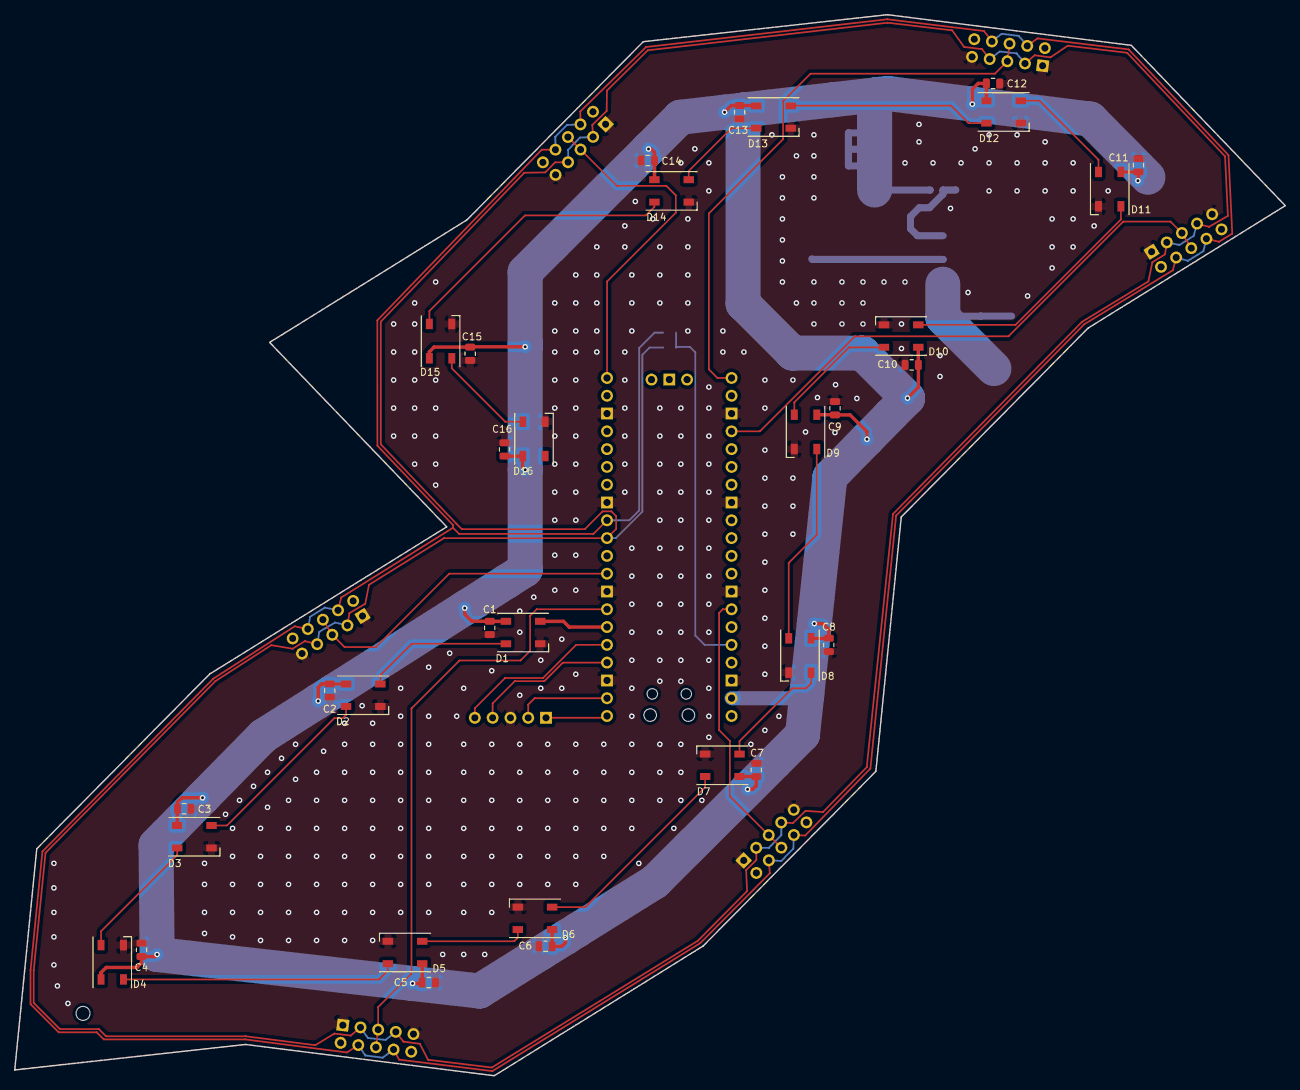
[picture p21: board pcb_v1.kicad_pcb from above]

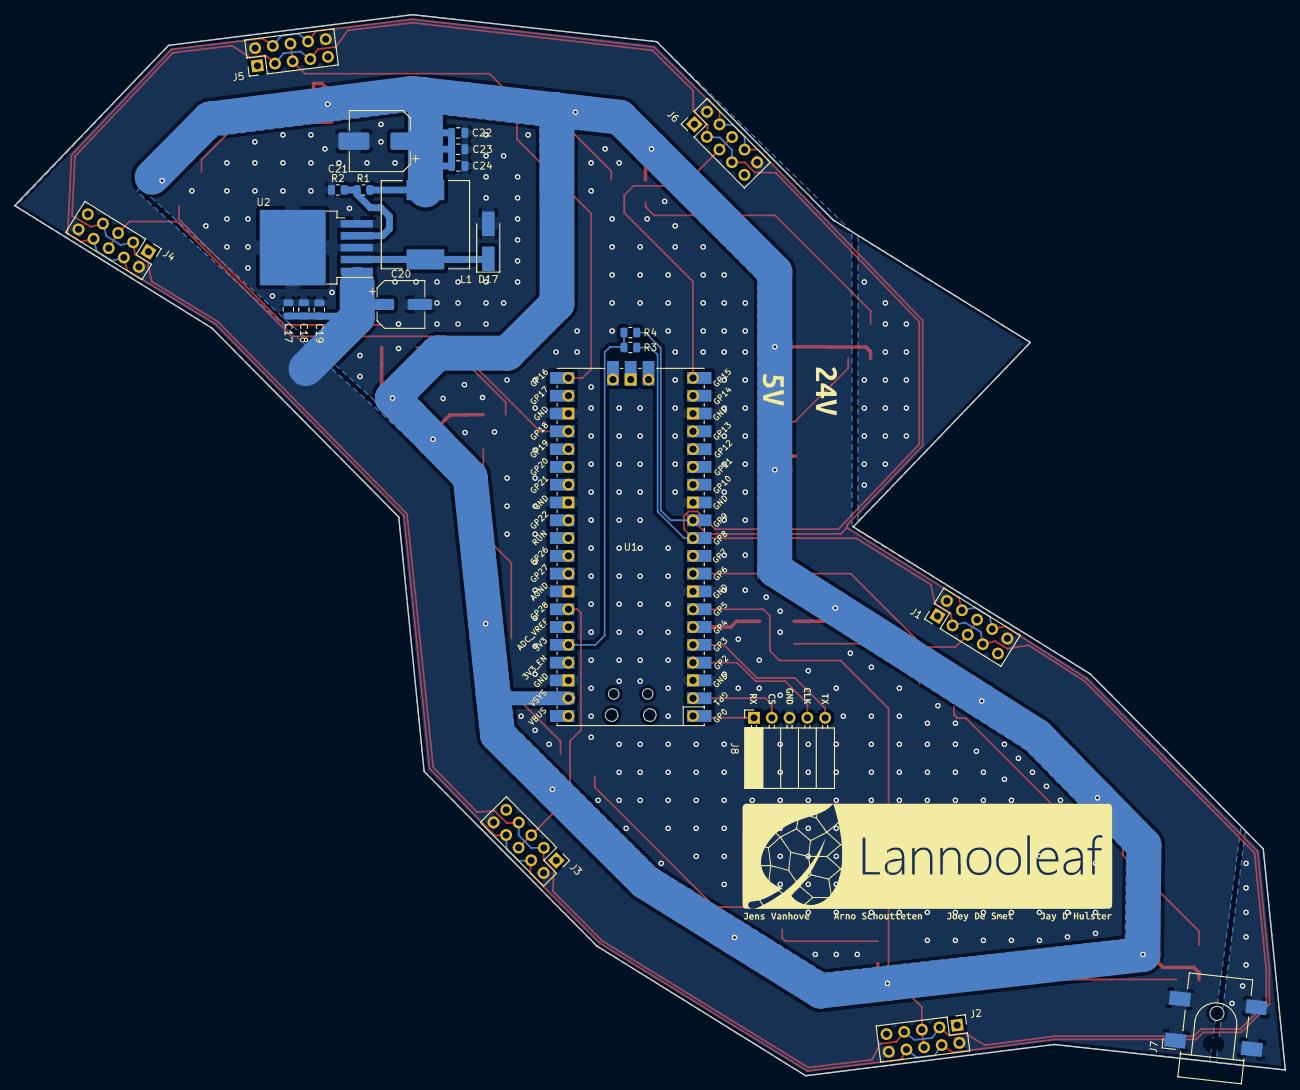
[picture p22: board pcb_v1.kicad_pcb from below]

Board: 2 copper layers, 181.4 x 151.5 mm, 67 parts (35 on the bottom side), 34 nets.

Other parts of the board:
kibuzzard-6233C5FE: G***; kibuzzard-6233C5FE
kibuzzard-6233C627: G***; kibuzzard-6233C627
kibuzzard-6233C655: G***; kibuzzard-6233C655
kibuzzard-6233C670: G***; kibuzzard-6233C670
kibuzzard-6234ACC3: G***; kibuzzard-6234ACC3
kibuzzard-6234ACD1: G***; kibuzzard-6234ACD1
kibuzzard-6234ACE5: G***; kibuzzard-6234ACE5
kibuzzard-6234ACFA: G***; kibuzzard-6234ACFA
kibuzzard-6234AD1C: G***; kibuzzard-6234AD1C
kibuzzard-6234B02F: G***; kibuzzard-6234B02F
kibuzzard-6234B014: G***; kibuzzard-6234B014

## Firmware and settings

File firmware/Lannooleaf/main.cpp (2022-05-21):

#include <array>
#include <memory>
#include <stdio.h>
#include <stdint.h>
#include <algorithm>

#include <pico/stdlib.h>
#include <pico/multicore.h>

#include <leaf.hpp>
#include <commands.hpp>
#include <controller.hpp>
#include <helper_funcs_var.hpp>

using namespace Lannooleaf;
using namespace Lannooleaf::interfaces;

std::unique_ptr< IUpdatable > unit = nullptr;

int main() {
  stdio_init_all();
  set_alive_led();

  for (select_pins pin : all_select_pins) {
    gpio_init(static_cast<uint> (pin));
    gpio_set_dir(static_cast<uint> (pin), GPIO_IN);
  }

  gpio_init(CS);
  gpio_set_dir(CS, GPIO_IN);
  gpio_pull_up(CS);

  gpio_pull_up(SDA);
  gpio_pull_up(SCL);

  uint32_t gpio_mask = 0;
  for (auto pin : all_select_pins) {
    gpio_mask |= 1 << (uint)pin; 
  }

  // Wait untill unit initialized as controller or leaf
  while (!unit) {
    uint32_t status = gpio_get_all();

    try {

      if (!(status & 1 << 1)) {
        unit = std::unique_ptr< IUpdatable > (new Controller);
        PRINT("Controller initialized\n");
      }

      if (status & gpio_mask) {
        unit = std::unique_ptr< IUpdatable > (new Leaf);
        PRINT("Leaf initialized\n");
      }

    } catch (std::runtime_error& e) {
      printf(e.what());
      error_blink();
    }

  }

  PRINT("Stating update loop\n");

  while (true)
    unit->update();
  
}

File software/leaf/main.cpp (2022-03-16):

#include <stdio.h>
#include <stdint.h>

#include <pico/stdlib.h>
#include <commands.h>
#include <helper_funcs_var.h>
#include <leaf.h>

using namespace LannoLeaf;

Leaf leaf((uint8_t) UNCONFIGUREDADDRESS, i2c0);

void set_alive_led(void) {
  #ifdef DEBUG
  const uint led_pin = 25;
  gpio_init(led_pin);
  gpio_set_dir(led_pin, GPIO_OUT);
  gpio_put(led_pin, true);
  #endif
}

void add_handlers(void) {
  leaf.add_command_handel(slave_set_i2c_address, [&](context* contx, msg_buff* msg){
    if (leaf.address() == 0x08) {
      leaf.address(msg -> buffer[0]);
    }
  });

  leaf.add_command_handel(slave_ping, [&](context* contx, msg_buff* msg){
    contx -> mem[0] = 0xA5;
    contx -> mem[1] = 0x5A;
  });

  leaf.add_command_handel(slave_reset_mem_counter, [&](context* contx, msg_buff* msg){
    contx -> mem_address = 0;
  });  

  leaf.add_command_handel(slave_set_sel_pin, [&](context* contx, msg_buff* msg){
    if (gpio_is_dir_out(msg -> buffer[0]) && !msg -> buffer[1]) {
      gpio_put(msg -> buffer[0], false);
      gpio_set_dir(msg -> buffer[0], GPIO_IN);
    } else {
      gpio_set_dir(msg -> buffer[0], GPIO_OUT);
      gpio_put(msg -> buffer[0], true);
    }
  });

  leaf.add_command_handel(slave_get_sel_pin, [&](context* contx, msg_buff* msg){
    contx -> mem[0] = leaf.sel_pin_status();
  });

  leaf.add_command_handel(slave_reset, [&](context* contx, msg_buff* msg){
    leaf.reset();
  });

  leaf.add_command_handel(slave_is_neighbor, [&](context* contx, msg_buff* msg){
    if (leaf.sel_pin_status()) {
      contx -> mem_address++;
      contx -> mem[contx -> mem_address] = msg -> buffer[0];
      
      contx -> mem_address++;
      contx -> mem[contx -> mem_address] = leaf.sel_pin_status();
    } 
  });

  leaf.add_command_handel(slave_neighbor_size, [&](context* contx, msg_buff* msg){
    contx -> mem[0] = (contx -> mem_address / 2);
    contx -> mem_address = 0;
  });

  leaf.add_command_handel(slave_set_led, [&](context* contx, msg_buff* msg){
    leaf.ledstrip.setPixelColor(msg -> buffer[0], PicoLed::RGBW(msg -> buffer[1], msg -> buffer[2], msg -> buffer[3], msg -> buffer[4]));
    leaf.ledstrip.show();
  });

  leaf.add_command_handel(slave_set_all_led, [&](context* contx, msg_buff* msg){
    printf("Received set all led message\r\n");
    leaf.ledstrip.fill(PicoLed::RGBW(msg -> buffer[0], msg -> buffer[1], msg -> buffer[2], msg -> buffer[3]));
    leaf.ledstrip.show();
  });

  leaf.add_command_handel(slave_set_brightness, [&](context* contx, msg_buff* msg){
    leaf.ledstrip.setBrightness(msg -> buffer[0]);
    leaf.ledstrip.show();
  });
}

int main() {
  stdio_init_all();
  set_alive_led();

  add_handlers();

  while (true) {
    while (!leaf.configured()) {
      leaf.update();
      if (leaf.sel_pin_status() && !leaf.slave_initialized()) leaf.slave_init();
    }

    while (leaf.configured()) {
      leaf.update();
    }
  }
}

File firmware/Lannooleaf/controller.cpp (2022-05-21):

/**
 * @file controller.cpp
 * @author Joey De Smet (Joey@de-smet.org)
 * @brief Source file to controller.h
 * @version 0.1
 * @date 2022-05-04
 * 
 * @copyright Copyright 2022 Joey De Smet
 * 
 *  Licensed under the Apache License, Version 2.0 (the "License");
 *  you may not use this file except in compliance with the License.
 *  You may obtain a copy of the License at
 * 
 *         http://www.apache.org/licenses/LICENSE-2.0
 * 
 *  Unless required by applicable law or agreed to in writing, software
 *  distributed under the License is distributed on an "AS IS" BASIS,
 *  WITHOUT WARRANTIES OR CONDITIONS OF ANY KIND, either express or implied.
 *  See the License for the specific language governing permissions and
 *  limitations under the License.
 */
#include <controller.hpp>

namespace Lannooleaf {

  Controller::Controller()
  : slave(spi0, MOSI, MISO, CLK, CS, BAUDRATE), leaf_master(i2c0, SDA, SCL, BAUDRATE) {
    add_handlers();

    for (auto pin : all_select_pins)
      gpio_set_dir((uint)pin, GPIO_OUT);

    graph.add_node(I2C_CONTOLLER_PLACEHOLDER_ADDRESS);

    device_discovery();
    topology_discovery();

    discover_animation(&ledstrip, { 0, 50, 100 });

    for (auto [address, node] : graph.map) {
      const uint8_t message = (uint8_t)slave_commands::discovery_done;
      leaf_master.send_data(address, &message, 1);

      sleep_ms(500);
    }
  }

  Controller::~Controller() { }

  // Good luck ;)
  void Controller::device_discovery(void) {
    bool controller_done = false;
    
    std::function <void(Node*)> search = [&](Node* node) {
      // Take note of which nodes have been visited
      visited.push_back(node -> i2c_address);

      for (select_pins pin : all_select_pins) {
        set_select_pin((uint)pin, true, node->i2c_address);
        sleep_ms(10); //! DO NOT REMOVE !

        uint8_t next_address = get_next_available_address();

        std::array<uint8_t, 2> set_next_address = { (uint8_t)slave_commands::set_i2c_address, next_address };
        leaf_master.send_data(GENCALLADR, 
                              set_next_address.data(), 
                              set_next_address.size());
        sleep_ms(SLEEP_TIME);

        const uint8_t ping = (uint8_t)slave_commands::ping;
        leaf_master.send_data(next_address, 
                              &ping, 
                              1);
        sleep_ms(SLEEP_TIME);

        std::array<uint8_t, 1> pong = { 0 };
        leaf_master.receive_data( next_address, 
                              pong.data(), 
                              pong.size());

        printf("Received: 0x%02x\n", pong.at(0));

        // If response add node to graph
        if (pong.at(0) == 0xa5) {
          printf("Pong received\n");
          graph.add_node(next_address); 
        }
        else next_address = UNCONFIGUREDADDRESS;

        // If current node is controller an it found another device add edge from controller to that device
        if (node->i2c_address == I2C_CONTOLLER_PLACEHOLDER_ADDRESS && next_address != UNCONFIGUREDADDRESS) 
          graph.add_edge(I2C_CONTOLLER_PLACEHOLDER_ADDRESS, sel_pin_to_side(pin), next_address);
        
        set_select_pin((uint)pin, false, node->i2c_address);
        
        if (node->i2c_address == I2C_CONTOLLER_PLACEHOLDER_ADDRESS && pin == select_pins::F) controller_done = true;
        if (!controller_done) continue;

        for (auto [i2c_address, node] : graph.map) {
          // Call search function on next avaiable node if it has not been visited yet
          if (std::find(visited.begin(), visited.end(), i2c_address) == visited.end()) search(node);
        }
      };
    };

    search(graph.map[I2C_CONTOLLER_PLACEHOLDER_ADDRESS]);
  }

  void Controller::topology_discovery(void) {
    for (auto [i2c_address, node] : graph.map) {
      for (select_pins pin : all_select_pins) {
        set_select_pin((uint)pin, true, i2c_address);
      
        // Send message to all slaves to take note of neighbor when one of select pins is high
        std::array<uint8_t, 2> message = { (uint8_t)slave_commands::is_neighbor, i2c_address };
        leaf_master.send_data(GENCALLADR, 
                              message.data(), 
                              message.size());
        sleep_ms(SLEEP_TIME);

        set_select_pin((uint)pin, false, i2c_address);
      }
    }

    for (auto [i2c_address, node] : graph.map) {
      // Skip controller we added controller edges in device discovery
      if (i2c_address == I2C_CONTOLLER_PLACEHOLDER_ADDRESS) continue;

      const uint8_t size_msg = (uint8_t) slave_commands::get_neigbor_size;
      leaf_master.send_data(i2c_address,
                            &size_msg,
                            1);
      sleep_ms(SLEEP_TIME);
    
      uint8_t neighbor_count = 0;
      leaf_master.receive_data( i2c_address, 
                            &neighbor_count, 
                            1);
      sleep_ms(SLEEP_TIME);

      const u_int8_t info_msg = (uint8_t) slave_commands::get_neighbor_information;
      leaf_master.send_data(i2c_address, 
                            &info_msg, 
                            1);
      sleep_ms(SLEEP_TIME);

      std::vector<std::pair<uint8_t, uint8_t>> neighbors;
      for (int i = 0; i < neighbor_count; i++) {
        uint8_t neighbor;
        uint8_t n_side;

        leaf_master.receive_data( i2c_address,
                              &neighbor,
                              1);
        sleep_ms(SLEEP_TIME);

        leaf_master.receive_data( i2c_address,
                              &n_side,
                              1);
        sleep_ms(SLEEP_TIME);

        neighbors.push_back(std::make_pair(neighbor, n_side));
      }
      
      for (auto [neighbor, side] : neighbors) {
        graph.add_edge( i2c_address, 
                        sel_pin_state_to_side(side), 
                        neighbor);
      }
    }

    graph.prepare_data();
  }

  void Controller::update(void) {
    if (slave.readable()) {
      try {
        uint8_t value_rw = slave.read_byte();

        if (value_rw == 0xa5) {
          static Packet pkt;
          pkt.data.clear();

          pkt.command = slave.read_byte();
          pkt.lenght = slave.read_byte();

          for (uint i = 0; i < pkt.lenght; i++)
            pkt.data.push_back(slave.read_byte());

          pkt.checksum = slave.read_byte();

          handel_packet(&pkt);
        }

        if (value_rw == 0x5a) {
          static Packet pkt;
          pkt.data.clear();

          pkt.command  = slave.read_byte();
          pkt.lenght   = slave.read_byte();
          pkt.checksum = slave.read_byte();

          handel_packet(&pkt);

          slave.write_byte(0xa5);
          slave.write_byte(pkt.command);
          slave.write_byte(pkt.lenght);

          for (uint i = 0; i < pkt.lenght; i++)
            slave.write_byte(pkt.data.at(i));

          slave.write_byte(pkt.checksum);
        }
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

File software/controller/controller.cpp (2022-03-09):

#include <controller.h>

namespace LannoLeaf {

  Controller::Controller(i2c_inst_t * i2c_leaf_inst) { 
    leaf_master.set_i2c_inst(i2c_leaf_inst);
    initialize();
  }

  Controller::~Controller() {}

  void Controller::initialize(void) {
    for (select_pins pin : all_select_pins) {
      gpio_init(pin);
      gpio_set_dir(pin, GPIO_OUT);
    }

    gpio_init(PICO_DEFAULT_I2C_SDA_PIN);
    gpio_set_function(PICO_DEFAULT_I2C_SDA_PIN, GPIO_FUNC_I2C);
    gpio_pull_up(PICO_DEFAULT_I2C_SDA_PIN);

    gpio_init(PICO_DEFAULT_I2C_SCL_PIN);
    gpio_set_function(PICO_DEFAULT_I2C_SCL_PIN, GPIO_FUNC_I2C);
    gpio_pull_up(PICO_DEFAULT_I2C_SCL_PIN);

    i2c_init(i2c0, BAUDRATE);

    uart_init(uart0, 9600);

    gpio_set_function(12, GPIO_FUNC_UART);
    gpio_set_function(13, GPIO_FUNC_UART);

    graph.add_node(I2C_CONTOLLER_PLACEHOLDER_ADDRESS);
  }

  void Controller::device_discovery(void) {
    std::function <void(Node*)> search = [&](Node* node) {
      this -> visited.push_back(node -> i2c_address);
      for (select_pins pin : all_select_pins) {
        if (node -> i2c_address == I2C_CONTOLLER_PLACEHOLDER_ADDRESS) gpio_put(pin, true);
        else this -> leaf_master.send_slave_message(node -> i2c_address, {
          slave_set_sel_pin,
          2,
          { (uint8_t)pin, 1 }
        });

        sleep_ms(10);

        uint8_t next_assigned_address = this -> assign_new_address();

        if (node -> i2c_address == I2C_CONTOLLER_PLACEHOLDER_ADDRESS) {
          gpio_put(pin, false);

          if (next_assigned_address != UNCONFIGUREDADDRESS) {
            graph.add_edge(I2C_CONTOLLER_PLACEHOLDER_ADDRESS, sel_pin_to_side(pin), next_assigned_address);
          }
        } else this -> leaf_master.send_slave_message(node -> i2c_address, {
          slave_set_sel_pin,
          2,
          { (uint8_t)pin, 0 }
        });

        std::map <uint8_t, Node*>::iterator itr;
        for (itr = this -> graph.map.begin(); itr != this -> graph.map.end(); itr++) {
          if (!std::count(this -> visited.begin(), this -> visited.end(), itr -> second -> i2c_address)) {
            search(itr -> second);
          }
        }
      };
    };

    search(graph.map[I2C_CONTOLLER_PLACEHOLDER_ADDRESS]);
  }

  void Controller::topology_discovery(void) {
    std::map <uint8_t, Node*>::iterator itr;
    for (itr = this -> graph.map.begin(); itr != this -> graph.map.end(); itr++) {
      for (select_pins pin : all_select_pins) {

        if (itr -> second -> i2c_address == I2C_CONTOLLER_PLACEHOLDER_ADDRESS) gpio_put(pin, true);
        else leaf_master.send_slave_message(itr -> second -> i2c_address, {
          slave_set_sel_pin,
          2,
          { (uint8_t)pin, 1 }
        });
      
        leaf_master.send_slave_message(GENCALLADR, {
          slave_is_neighbor,
          1,
          { itr -> second -> i2c_address }
        });

        if (itr -> second -> i2c_address == I2C_CONTOLLER_PLACEHOLDER_ADDRESS) gpio_put(pin, false);
        else leaf_master.send_slave_message(itr -> second -> i2c_address, {
          slave_set_sel_pin,
          2,
          { (uint8_t)pin, 0 }
        });
      }
    }

    for (itr = this -> graph.map.begin(); itr != this -> graph.map.end(); itr++ ) {
      if (itr -> second -> i2c_address == I2C_CONTOLLER_PLACEHOLDER_ADDRESS) continue;

      leaf_master.send_slave_message(itr -> second -> i2c_address, {
        slave_neighbor_size,
        0,
        { }
      });

      leaf_master.get_slave_data_no_mem_reset(itr -> second -> i2c_address, 1);

      uint8_t neigbor_count = leaf_master.memory[0];
      leaf_master.get_slave_data(itr -> second -> i2c_address, neigbor_count * 2);

      for (uint8_t i = 0; i <= neigbor_count; i += 2) {
        graph.add_edge(itr -> second -> i2c_address, sel_pin_state_to_side(leaf_master.memory[i + 1]), leaf_master.memory[i]);
      }
    }
  }

  void Controller::reset(void) {
    leaf_master.send_slave_message(GENCALLADR, {
      slave_reset,
      0,
      { }
    });

    graph.clear();
    visited.clear();
    graph.add_node(I2C_CONTOLLER_PLACEHOLDER_ADDRESS);

    device_discovery();
    topology_discovery();
  }

  void Controller::handel_packet(packet pkt) {
    std::map<bl_commands, std::function<void(packet)>>::iterator itr = packet_handlers.find((bl_commands) pkt.command);
    if (itr != packet_handlers.end()) packet_handlers[(bl_commands)pkt.command](pkt);
  }

  void Controller::add_packet_handel(bl_commands cmd, std::function<void(packet)> func) {
    std::map<bl_commands, std::function<void(packet)>>::iterator itr = packet_handlers.find(cmd);

    if (itr == packet_handlers.end()) {
      packet_handlers[cmd] = func;
    }
  }

  uint8_t Controller::assign_new_address(void) {
    uint8_t next_address = get_next_available_address();

    leaf_master.send_slave_message(GENCALLADR, {
      slave_set_i2c_address,
      1,
      { next_address }
    });

    leaf_master.send_slave_message(next_address, {
      slave_ping,
      1,
      { 2 }
    });

    leaf_master.get_slave_data(next_address, 2);

    if (leaf_master.memory[0] == 0xA5 && leaf_master.memory[1] == 0x5A) {
      leaf_master.reset_mem();
      graph.add_node(next_address);
      return next_address;
    }

    return UNCONFIGUREDADDRESS;
  }

  uint8_t Controller::get_next_available_address(void) {
    for (uint8_t addr = 0; addr < (1 << 7); ++addr) {
      if (graph.map.find(addr) == graph.map.end() && !reserved_addr(addr)) {
        return addr;
      }
    }
    return (uint8_t) UNCONFIGUREDADDRESS;
  }

}

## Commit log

2022-02-23 Added basic i²c communication & device detection
2022-02-23 leave shape
    [Body2.stl, LannooLeaf_v1.ipt, LannooLeave v1.stl]
2022-02-23 inline dxf
    [pcb-inline.dxf]
2022-02-23 inline fix
    [pcb-inline.dxf]
2022-02-23 updated pcbv1
    [pcb_v1.kicad_pcb, pcb_v1.kicad_sch]
2022-02-25 pcbv1 updated (MC34166 added)
    [pcb_v1.kicad_pcb, pcb_v1.kicad_sch, tussenstukpw22.kicad_pcb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]
2022-03-09 eeewojoooooooo videoooooooo :)
    [prototype1.stl]
2022-03-09 TL2575-05 added
    [pcb_v1.kicad_pcb, pcb_v1.kicad_sch]
2022-03-11 worked on pcbv1
    [pcb_v1.kicad_pcb, pcb_v1.kicad_sch]
2022-03-13 finished pcbv1
    [pcb_v1.kicad_pcb, pcb_v1.kicad_sch]
2022-03-14 updated pcb
    [pcb_v1.kicad_pcb]
2022-03-16 Made some changes to uart command handeling
2022-03-20 pcb updated
    [pcb_v1.kicad_pcb, pcb_v1.kicad_sch, tussenstukpw22.kicad_sch]
2022-03-21 aliexpress BOM
2022-03-21 modified pcb
    [pcb_v1.kicad_pcb, pcb_v1.kicad_sch, tussenstukpw22.kicad_pcb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]
2022-03-22 Added spi communication
2022-03-22 Removed spi branch
2022-03-22 added javascript for communication over spi with controller
2022-03-30 shape fusion
    [LannooLeave v4.f3d]
2022-03-30 changes pcb
    [tussenstukpw22.kicad_pcb]
2022-03-31 Redesigned I2c_master & multicore
    [controller.cpp, graph.cpp, helper_funcs_var.cpp]
2022-04-03 changes made
    [pcb_v1.kicad_pcb]
2022-04-12 Made changes to Spi and I2c slave, project now compiles to one singular file
2022-04-29 Replaced std::queue with pico queue to be thread safe
    [controller.cpp, i2c_slave.cpp, main.cpp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]
2022-05-03 cleanded up software folder
    [Lannoof v7.f3d, prototype2.stl, prototype3.stl]
2022-05-05 repo cleanup
    [LannooLeaf_v1.ipt, LannooLeave v1.stl, tolerance_check.stl]
2022-05-05 Renamed I2CSlave and SPISlave class
2022-05-10 Major changes to spi and i2c
